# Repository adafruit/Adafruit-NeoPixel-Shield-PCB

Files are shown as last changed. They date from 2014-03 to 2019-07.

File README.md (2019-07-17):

## Adafruit NeoPixel Shield for Arduino - 40 RGB LED Pixel Matrix PCB

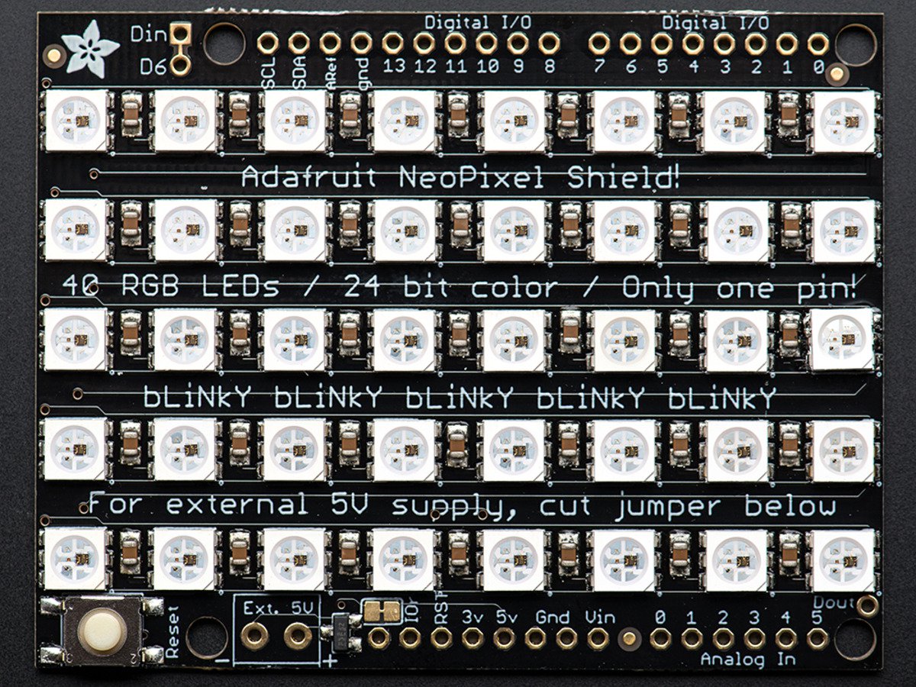
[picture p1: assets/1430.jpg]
<a href="http://www.adafruit.com/products/1430"><br/>
Click here to purchase one from the Adafruit shop</a>

PCB files for the Adafruit NeoPixel Shield for Arduino - 40 RGB LED Pixel Matrix. Format is EagleCAD schematic and board layout
* https://www.adafruit.com/product/1430

### Description

Put on your sunglasses before putting this shield onto your 'duino - 40 eye-blistering RGB LEDs adorn the NeoPixel shield for a blast of configurable color. Arranged in a 5x8 matrix, each pixel is individually addressable. Only one pin (Digital #6) is required to control all the LEDs. You can cut a trace and use nearly any other pin if you need some customization.

To make it easy to start, the LEDs are by default powered from the 5V onboard Arduino supply. As long as you aren't lighting up all the pixels full power white that should be fine. If you want to power the shield with an external power supply, solder in the included terminal block (pro-tip: put it on the bottom of the board so it doesn't stick up) to wire in an external 4-6VDC power supply - that power supply will also power the Arduino and shield. If you want to use the terminal block to power the shield but keep the Arduino itself on DC or USB power only, cut the center of the solder jumper to the right of the terminal block. There's a polarity protection FET on the external input in case you wire the power backwards (we would never do that, it was, umm, a friend of ours, yeah that's it!)

If, say, you need MORE blinky, you can chain these together. For the second shield, connect the DIN connection to the first shield's DOUT. Also connect a ground pin together and power with 5V. There you go! You can chain as many as you'd like although after 5 or more shields you may run low on RAM if you're using an UNO.

We include both stacking headers and plain headers. Use whichever you prefer - there isn't a lot of space left over for the 'duino pin breakouts so if you want to wire up some other outputs or sensors the stacking headers are good. For a slim sturdy look, solder on the plain headers.

[Our detailed NeoPixel Uberguide has everything you need to use NeoPixels in any shape and size. Including ready-to-go library & example code for the Arduino UNO/Duemilanove/Diecimila, Flora/Micro/Leonardo, Trinket/Gemma, Arduino Due & Arduino Mega/ADK (all versions)](http://learn.adafruit.com/adafruit-neopixel-uberguide)

**Note**: The terminal blocks included with your product may be blue or black.

### License

Adafruit invests time and resources providing this open source design, please support Adafruit and open-source hardware by purchasing products from [Adafruit](https://www.adafruit.com)!

Designed by Limor Fried/Ladyada for Adafruit Industries.

Creative Commons Attribution/Share-Alike, all text above must be included in any redistribution. See license.txt for additional details.

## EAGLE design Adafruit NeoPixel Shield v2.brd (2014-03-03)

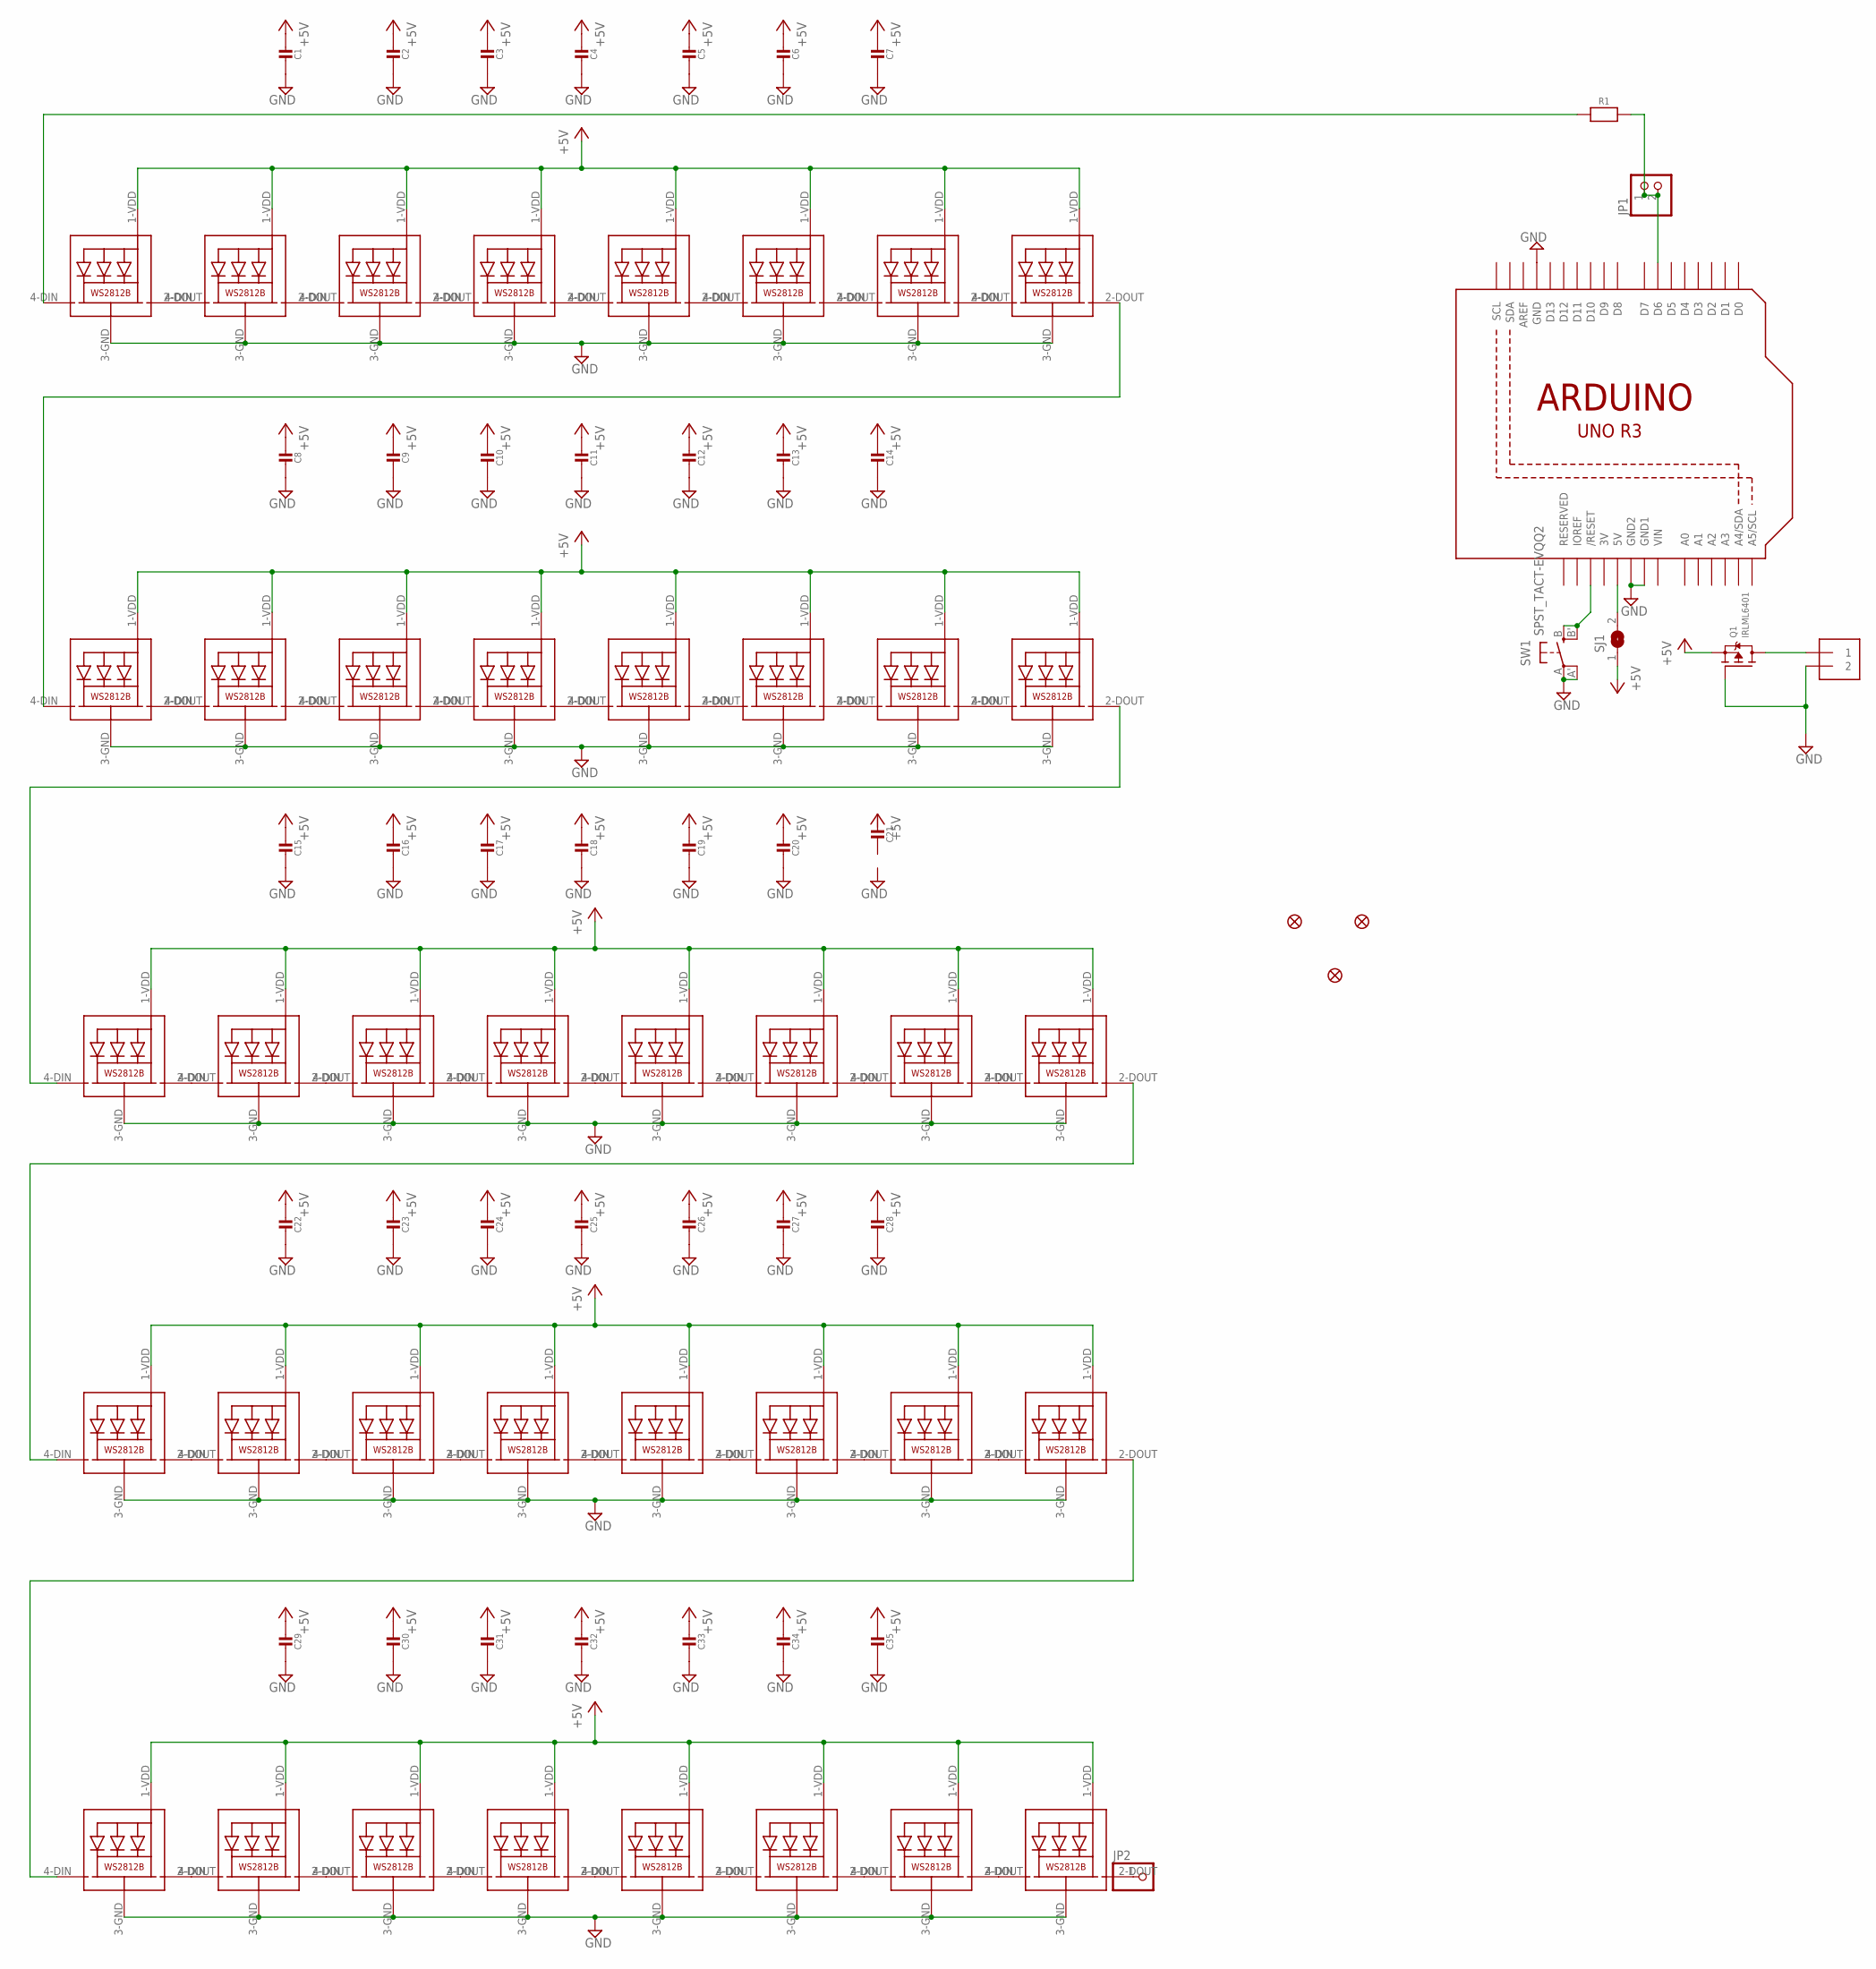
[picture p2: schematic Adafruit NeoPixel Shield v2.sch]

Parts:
C1, C2, C3, C4, C5, C6, C7, C8, C9, C10, C11, C12, C13, C14, C15, C16, C17, C18, C19, C20, C21, C22, C23, C24, C25, C26, C27, C28, C29, C30, C31, C32, C33, C34, C35: CAP_CERAMIC_0805NO; _0805NO
FID1, FID2, FID3: FIDUCIAL""; FIDUCIAL_1MM
J1: 1X2-3.5MM
JP1: HEADER-1X2ROUND; 1X02_ROUND
JP2: PINHD-1X1CB; 1X01-CLEANBIG
LED1, LED2, LED3, LED4, LED5, LED6, LED7, LED8, LED9, LED10, LED11, LED12, LED13, LED14, LED15, LED16, LED17, LED18, LED19, LED20, LED21, LED22, LED23, LED24, LED25, LED26, LED27, LED28, LED29, LED30, LED31, LED32, LED33, LED34, LED35, LED36, LED37, LED38, LED39, LED40: WS2812B5050; WS2812B
Q1: IRLML6401; SOT23-WIDE
R1: RESISTOR_0805NO; _0805NO
SJ1: SOLDERJUMPERCLOSED; SOLDERJUMPER_CLOSEDWIRE
SW1: SPST_TACT-EVQQ2; EVQ-Q2
U1: ARDUINOR3-BPLACE

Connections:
3V: U1.3V
+5V: C1.1, C2.1, C3.1, C4.1, C5.1, C6.1, C7.1, C8.1, C9.1, C10.1, C11.1, C12.1, C13.1, C14.1, C15.1, C16.1, C17.1, C18.1, C19.1, C20.1, C21.1, C22.1, C23.1, C24.1, C25.1, C26.1, C27.1, C28.1, C29.1, C30.1, C31.1, C32.1, C33.1, C34.1, C35.1, LED1.1-VDD (VDD), LED2.1-VDD (VDD), LED3.1-VDD (VDD), LED4.1-VDD (VDD), LED5.1-VDD (VDD), LED6.1-VDD (VDD), LED7.1-VDD (VDD), LED8.1-VDD (VDD), LED9.1-VDD (VDD), LED10.1-VDD (VDD), LED11.1-VDD (VDD), LED12.1-VDD (VDD), LED13.1-VDD (VDD), LED14.1-VDD (VDD), LED15.1-VDD (VDD), LED16.1-VDD (VDD), LED17.1-VDD (VDD), LED18.1-VDD (VDD), LED19.1-VDD (VDD), LED20.1-VDD (VDD), LED21.1-VDD (VDD), LED22.1-VDD (VDD), LED23.1-VDD (VDD), LED24.1-VDD (VDD), LED25.1-VDD (VDD), LED26.1-VDD (VDD), LED27.1-VDD (VDD), LED28.1-VDD (VDD), LED29.1-VDD (VDD), LED30.1-VDD (VDD), LED31.1-VDD (VDD), LED32.1-VDD (VDD), LED33.1-VDD (VDD), LED34.1-VDD (VDD), LED35.1-VDD (VDD), LED36.1-VDD (VDD), LED37.1-VDD (VDD), LED38.1-VDD (VDD), LED39.1-VDD (VDD), LED40.1-VDD (VDD), Q1.2 (S), SJ1.1
GND: C1.2, C2.2, C3.2, C4.2, C5.2, C6.2, C7.2, C8.2, C9.2, C10.2, C11.2, C12.2, C13.2, C14.2, C15.2, C16.2, C17.2, C18.2, C19.2, C20.2, C21.2, C22.2, C23.2, C24.2, C25.2, C26.2, C27.2, C28.2, C29.2, C30.2, C31.2, C32.2, C33.2, C34.2, C35.2, J1.2, LED1.3-GND (GND), LED2.3-GND (GND), LED3.3-GND (GND), LED4.3-GND (GND), LED5.3-GND (GND), LED6.3-GND (GND), LED7.3-GND (GND), LED8.3-GND (GND), LED9.3-GND (GND), LED10.3-GND (GND), LED11.3-GND (GND), LED12.3-GND (GND), LED13.3-GND (GND), LED14.3-GND (GND), LED15.3-GND (GND), LED16.3-GND (GND), LED17.3-GND (GND), LED18.3-GND (GND), LED19.3-GND (GND), LED20.3-GND (GND), LED21.3-GND (GND), LED22.3-GND (GND), LED23.3-GND (GND), LED24.3-GND (GND), LED25.3-GND (GND), LED26.3-GND (GND), LED27.3-GND (GND), LED28.3-GND (GND), LED29.3-GND (GND), LED30.3-GND (GND), LED31.3-GND (GND), LED32.3-GND (GND), LED33.3-GND (GND), LED34.3-GND (GND), LED35.3-GND (GND), LED36.3-GND (GND), LED37.3-GND (GND), LED38.3-GND (GND), LED39.3-GND (GND), LED40.3-GND (GND), Q1.1 (G), SW1.A, SW1.A' (P1), U1.GND, U1.GND1, U1.GND2
unnamed: LED1.2-DOUT (DO), LED2.4-DIN (DI)
unnamed: LED2.2-DOUT (DO), LED3.4-DIN (DI)
unnamed: LED3.2-DOUT (DO), LED4.4-DIN (DI)
unnamed: LED4.2-DOUT (DO), LED5.4-DIN (DI)
unnamed: LED5.2-DOUT (DO), LED6.4-DIN (DI)
unnamed: LED6.2-DOUT (DO), LED7.4-DIN (DI)
unnamed: LED7.2-DOUT (DO), LED8.4-DIN (DI)
unnamed: LED9.2-DOUT (DO), LED10.4-DIN (DI)
unnamed: LED10.2-DOUT (DO), LED11.4-DIN (DI)
unnamed: LED11.2-DOUT (DO), LED12.4-DIN (DI)
unnamed: LED12.2-DOUT (DO), LED13.4-DIN (DI)
unnamed: LED13.2-DOUT (DO), LED14.4-DIN (DI)
unnamed: LED14.2-DOUT (DO), LED15.4-DIN (DI)
unnamed: LED15.2-DOUT (DO), LED16.4-DIN (DI)
unnamed: LED8.2-DOUT (DO), LED9.4-DIN (DI)
unnamed: LED17.2-DOUT (DO), LED18.4-DIN (DI)
unnamed: LED18.2-DOUT (DO), LED19.4-DIN (DI)
unnamed: LED19.2-DOUT (DO), LED20.4-DIN (DI)
unnamed: LED20.2-DOUT (DO), LED21.4-DIN (DI)
unnamed: LED21.2-DOUT (DO), LED22.4-DIN (DI)
unnamed: LED22.2-DOUT (DO), LED23.4-DIN (DI)
unnamed: LED23.2-DOUT (DO), LED24.4-DIN (DI)
unnamed: LED16.2-DOUT (DO), LED17.4-DIN (DI)
unnamed: LED25.2-DOUT (DO), LED26.4-DIN (DI)
unnamed: LED26.2-DOUT (DO), LED27.4-DIN (DI)
unnamed: LED27.2-DOUT (DO), LED28.4-DIN (DI)
unnamed: LED28.2-DOUT (DO), LED29.4-DIN (DI)
unnamed: LED29.2-DOUT (DO), LED30.4-DIN (DI)
unnamed: LED30.2-DOUT (DO), LED31.4-DIN (DI)
unnamed: LED31.2-DOUT (DO), LED32.4-DIN (DI)
unnamed: LED24.2-DOUT (DO), LED25.4-DIN (DI)
unnamed: LED33.2-DOUT (DO), LED34.4-DIN (DI)
unnamed: LED34.2-DOUT (DO), LED35.4-DIN (DI)
unnamed: LED35.2-DOUT (DO), LED36.4-DIN (DI)
unnamed: LED36.2-DOUT (DO), LED37.4-DIN (DI)
unnamed: LED37.2-DOUT (DO), LED38.4-DIN (DI)
unnamed: LED38.2-DOUT (DO), LED39.4-DIN (DI)
unnamed: LED39.2-DOUT (DO), LED40.4-DIN (DI)
unnamed: LED32.2-DOUT (DO), LED33.4-DIN (DI)
unnamed: SW1.B (S), SW1.B' (S1), U1.RESET (/RESET)
unnamed: SJ1.2, U1.5V
unnamed: JP2.1, LED40.2-DOUT (DO)
unnamed: LED1.4-DIN (DI), R1.1
unnamed: JP1.1, JP1.2, R1.2, U1.D6
PWRIN: J1.1, Q1.3 (D)
VIN: U1.VIN

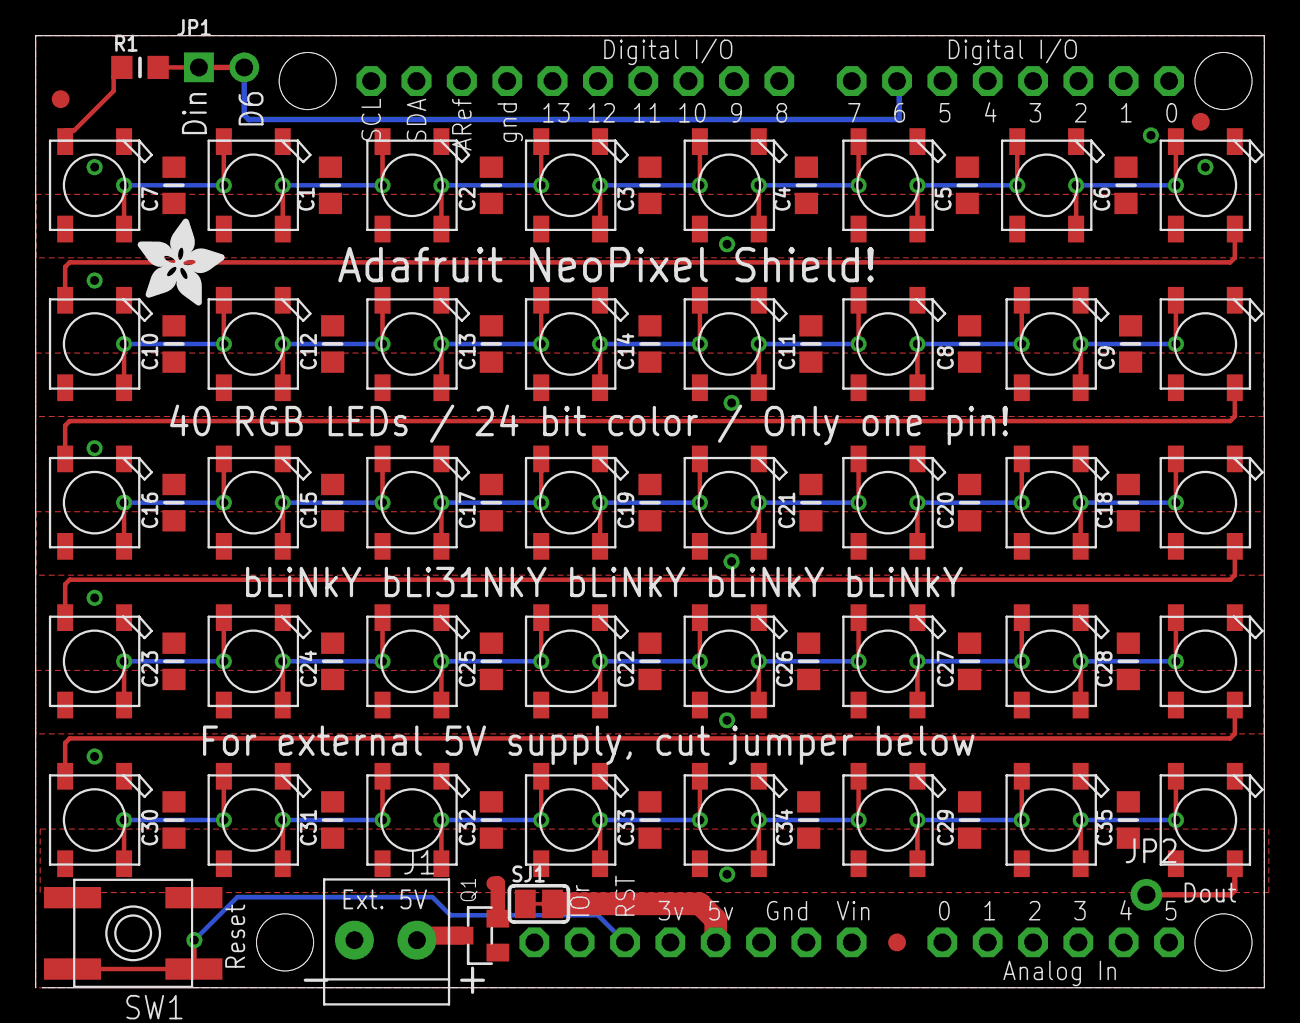
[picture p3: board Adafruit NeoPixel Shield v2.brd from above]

Board: 2 copper layers, 68.8 x 53.3 mm, 88 parts (1 on the bottom side), 47 nets.

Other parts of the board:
U$1: ADAFRUIT_5MM
U$2: ADAFRUIT_TEXT_30MM

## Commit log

2014-03-03 woo files!
    [Adafruit NeoPixel Shield v2.brd, Adafruit NeoPixel Shield v2.sch]
2019-07-17 updated to use cookiecutter for pcb repos

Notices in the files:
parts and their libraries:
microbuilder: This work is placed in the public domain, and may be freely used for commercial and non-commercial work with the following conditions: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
